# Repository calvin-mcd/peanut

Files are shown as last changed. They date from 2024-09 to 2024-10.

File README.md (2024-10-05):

# peanut

alice like 30% inspired by littol and tsuru. Case design, layout and concept by calumwri. Pcb by calvin0563

## Layout

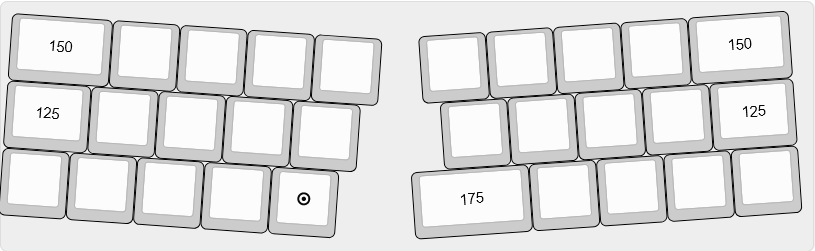
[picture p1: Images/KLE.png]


[Link](http://www.keyboard-layout-editor.com/#/gists/5c7a74c8b3bbc1b4ac3f81c209dc5aab)

## Case & Plate

Case and plate files are included in the respective folder.

The case requires m2x3mm heat set inserts and 3mm silicone inserts for the feet.

## Firmware

Flash file and source code included in the respective folder.

## Pictures

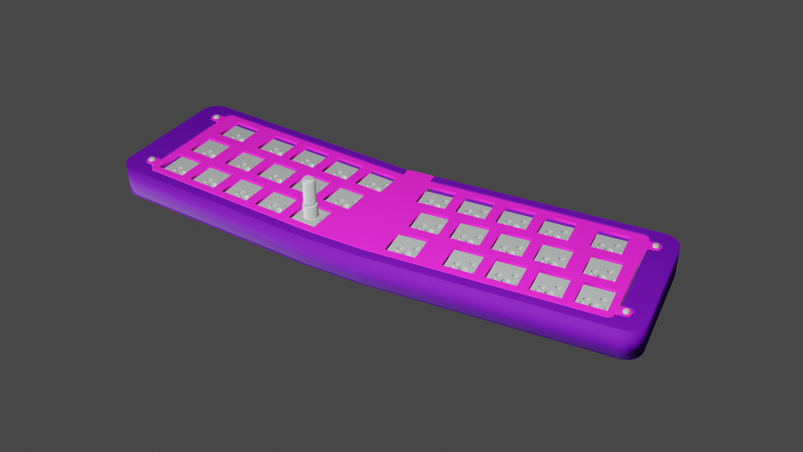
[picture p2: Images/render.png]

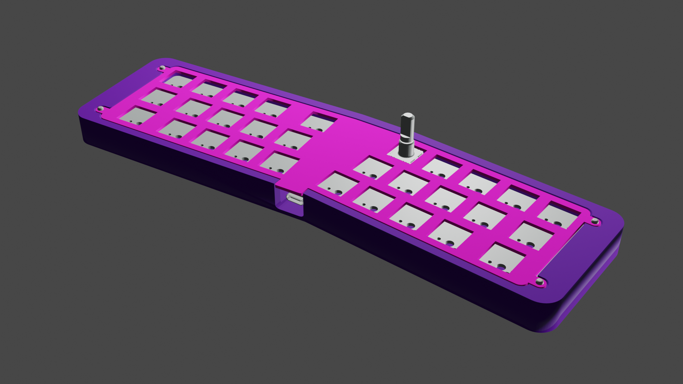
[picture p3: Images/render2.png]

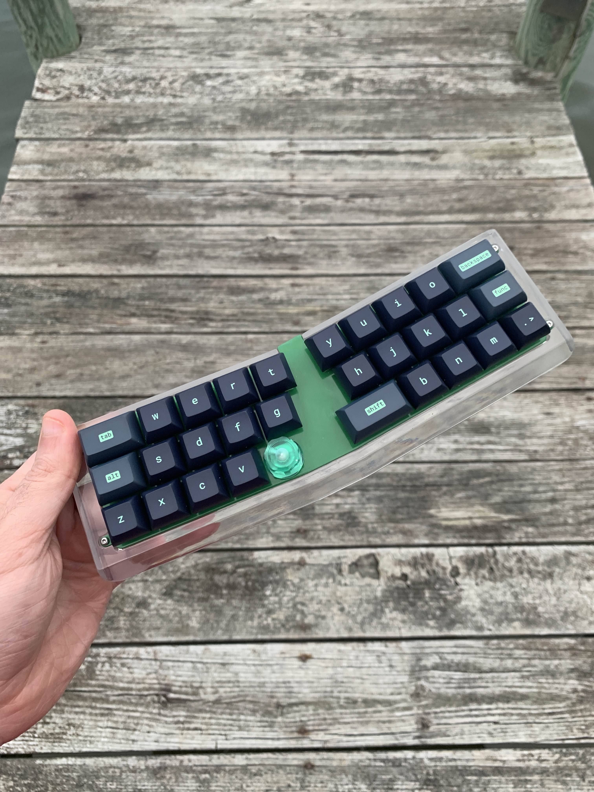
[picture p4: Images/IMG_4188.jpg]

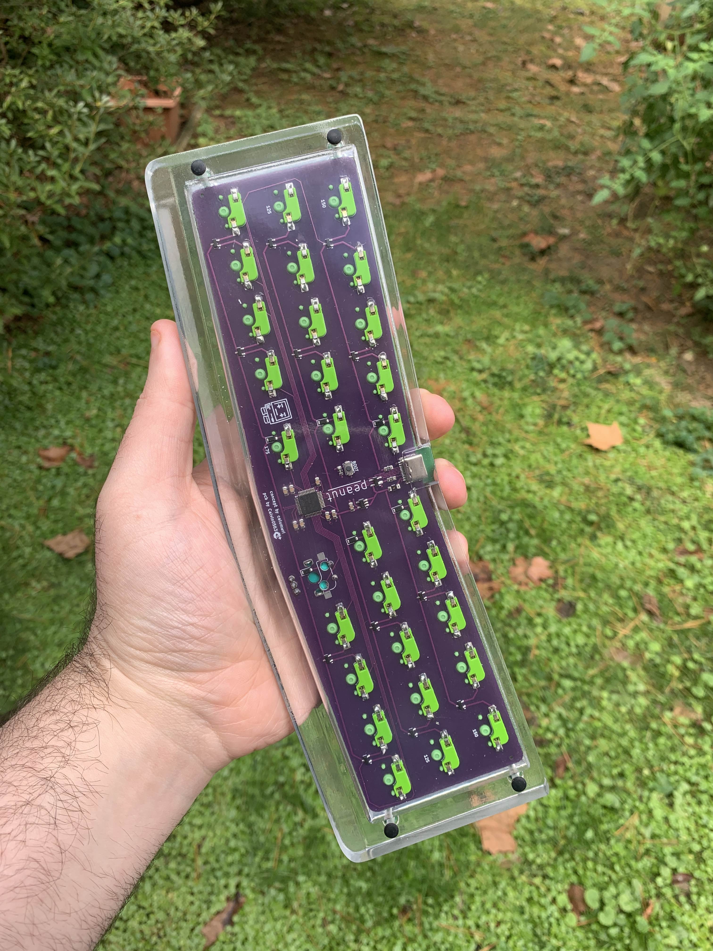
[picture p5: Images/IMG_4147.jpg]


## Todo

- [X] order & test pcb
- [X] test case
- [X] create firmware

## Disclaimer

This PCB has been fully tested and confirmed to work. The members of the PCB development team are however not liable if you end up with a non-functional pcb. Order at your own risk. Support will not be provided but pull requests will be reviewed and possibly accepted.

## License

This project is released under the GPL v3 License. Please refer to the LICENCE file.

## Credits

As always big thanks to the many people who helped me and inspired this board!

Any questions, contact Calvin0563 on Discord.

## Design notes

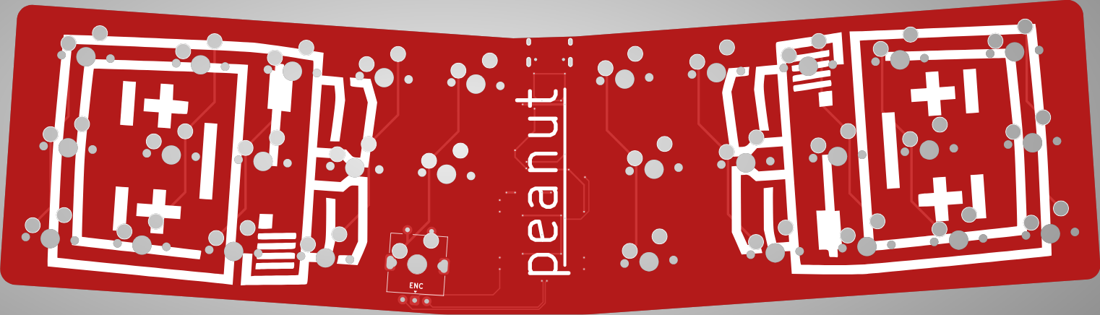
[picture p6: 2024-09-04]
Images/top.png

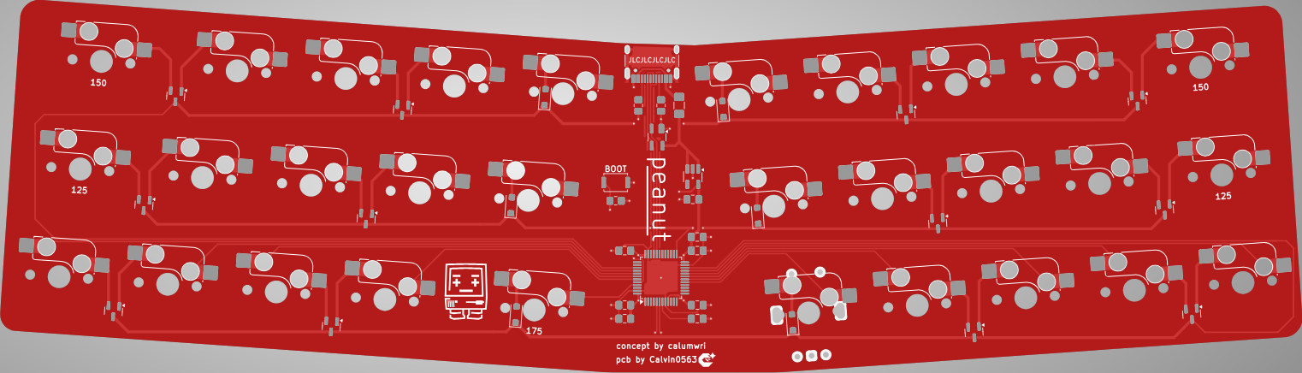
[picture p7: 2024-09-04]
Images/bottom.png

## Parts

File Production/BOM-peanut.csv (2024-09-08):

Comment | Designator | Footprint | LCSC
5.1k | R2,R3 | R_0805_2012Metric_Pad1.20x1.40mm_HandSolder | C118848
1nF | C8 | C_0805_2012Metric_Pad1.18x1.45mm_HandSolder | C7419428
500mA | F1 | Fuse_1206_3216Metric_Pad1.42x1.75mm_HandSolder | C135341
10uF | C6 | C_0805_2012Metric_Pad1.18x1.45mm_HandSolder | C15850
10k | R1 | R_0805_2012Metric_Pad1.20x1.40mm_HandSolder | C17414
100nF | C1,C2,C3,C4,C5,C7 | C_0805_2012Metric_Pad1.18x1.45mm_HandSolder | C28233
PRTR5V0U2X | U3 | SOT-143_Handsoldering | C2827688
USB_C_Receptacle_USB2.0 | J1 | USB_C_Receptacle_HRO_TYPE-C-31-M-12 | C165948
AP2112K-3.3 | U2 | SOT-23-5_HandSoldering | C3021085
BAV70_Small | D1,D10,D11,D12,D13,D14,D2,D3,D4,D7,D8,D9 | SOT-23 | C5184417
SKQGABE010 | SW2 | SW_Push_SPST_NO_Alps_SKRK | C561519
D_Small | D15,D16,D25,D26,D5,D6 | D_SOD-123F | C64898
STM32F072C8Tx | U1 | LQFP-48_7x7mm_P0.5mm | C80488

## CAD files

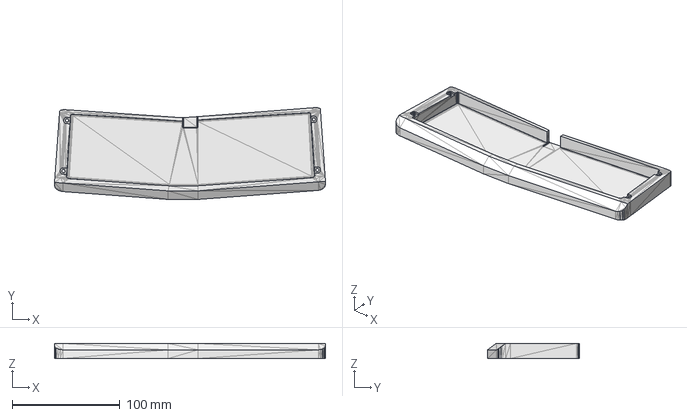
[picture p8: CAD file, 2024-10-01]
Case & Plate/peanut2.step
251.7 x 85.3 x 14.1 mm

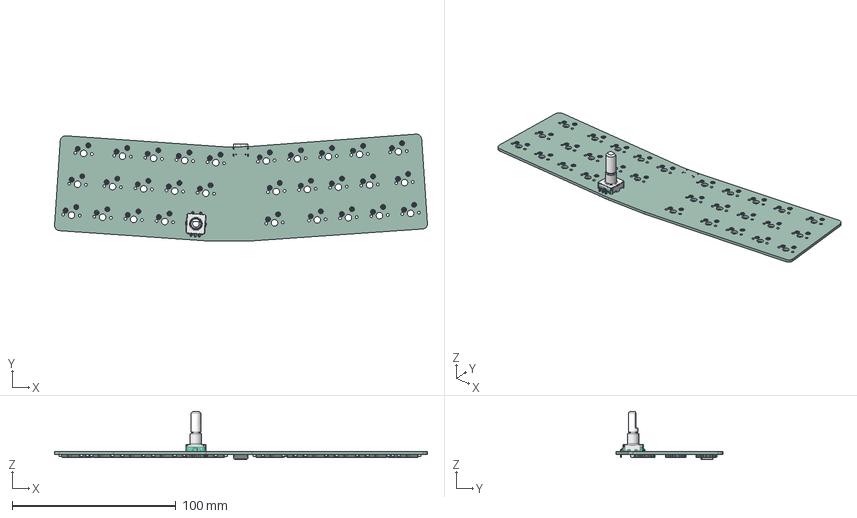
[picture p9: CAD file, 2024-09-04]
Project/peanut.step
227.9 x 65.3 x 29.4 mm
(Unsaved)
Kailh Hotswap v2 x 30
CON_TYPE-C-31-M-12 v3
_autosave-tsuru alice_PCB

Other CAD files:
Case & Plate/peanut2.stl

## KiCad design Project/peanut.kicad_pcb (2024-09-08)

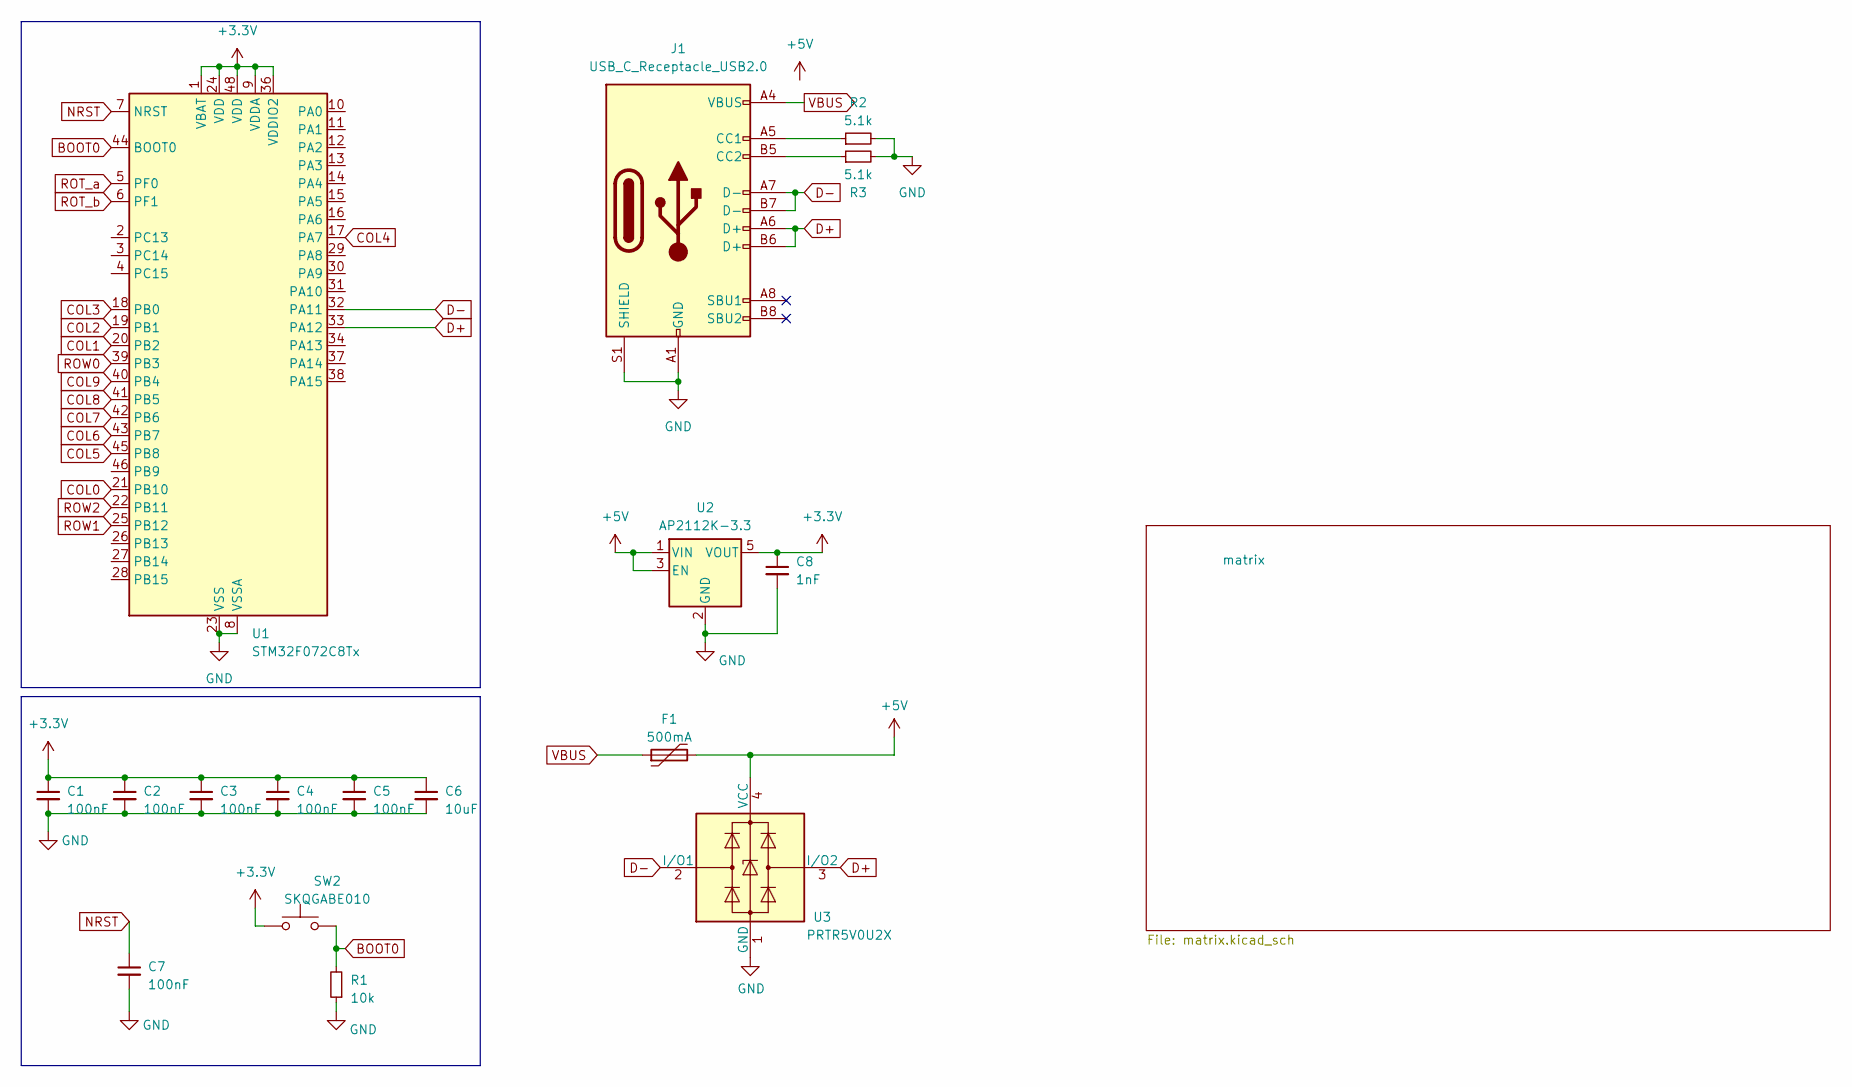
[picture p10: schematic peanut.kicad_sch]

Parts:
C1, C2, C3, C4, C5, C7: 100nF; C_0805_2012Metric_Pad1.18x1.45mm_HandSolder
C6: 10uF; C_0805_2012Metric_Pad1.18x1.45mm_HandSolder
C8: 1nF; C_0805_2012Metric_Pad1.18x1.45mm_HandSolder; LCSC Part Number C129637
F1: 500mA; Fuse_1206_3216Metric_Pad1.42x1.75mm_HandSolder; LCSC C135341
J1: USB_C_Receptacle_USB2.0; USB_C_Receptacle_HRO_TYPE-C-31-M-12; LCSC Part Number C3001293
R1: 10k; R_0805_2012Metric_Pad1.20x1.40mm_HandSolder
R2, R3: 5.1k; R_0805_2012Metric_Pad1.20x1.40mm_HandSolder
SW2: SKQGABE010; SW_Push_SPST_NO_Alps_SKRK; LCSC C115351
U1: STM32F072C8Tx; LQFP-48_7x7mm_P0.5mm
U2: AP2112K-3.3; SOT-23-5_HandSoldering; MPN AP2112K-3.3; LCSC Part Number C3021085
U3: PRTR5V0U2X; SOT-143_Handsoldering; LCSC C2827688

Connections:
+3.3V: C1.1, C2.1, C3.1, C4.1, C5.1, C6.1, C8.1, SW2.1, U1.1 (VBAT), U1.9 (VDDA), U1.24 (VDD), U1.36 (VDDIO2), U1.48 (VDD), U2.5 (VOUT)
+5V: F1.2, U2.1 (VIN), U2.3 (EN), U3.4 (VCC)
BOOT0: R1.2, SW2.2, U1.44 (BOOT0)
COL0: U1.21 (PB10); also elsewhere on the board
COL1: U1.20 (PB2); also elsewhere on the board
COL2: U1.19 (PB1); also elsewhere on the board
COL3: U1.18 (PB0); also elsewhere on the board
COL4: U1.17 (PA7); also elsewhere on the board
COL5: U1.45 (PB8); also elsewhere on the board
COL6: U1.43 (PB7); also elsewhere on the board
COL7: U1.42 (PB6); also elsewhere on the board
COL8: U1.41 (PB5); also elsewhere on the board
COL9: U1.40 (PB4); also elsewhere on the board
D+: J1.A6 (D+), J1.B6 (D+), U1.33 (PA12), U3.3 (I/O2)
D-: J1.A7 (D-), J1.B7 (D-), U1.32 (PA11), U3.2 (I/O1)
GND: C1.2, C2.2, C3.2, C4.2, C5.2, C6.2, C7.2, C8.2, J1.A1 (GND), J1.A12 (GND), J1.B1 (GND), J1.B12 (GND), J1.S1 (SHIELD), R1.1, R2.2, R3.2, U1.8 (VSSA), U1.23 (VSS), U1.35 (VSS), U1.47 (VSS), U2.2 (GND), U3.1 (GND); also elsewhere on the board
NRST: C7.1, U1.7 (NRST)
unnamed: J1.A5 (CC1), R2.1
unnamed: J1.B5 (CC2), R3.1
ROT_a: U1.5 (PF0); also elsewhere on the board
ROT_b: U1.6 (PF1); also elsewhere on the board
ROW0: U1.39 (PB3); also elsewhere on the board
ROW1: U1.25 (PB12); also elsewhere on the board
ROW3: U1.22 (PB11); also elsewhere on the board
VBUS: F1.1, J1.A4 (VBUS), J1.A9 (VBUS), J1.B4 (VBUS), J1.B9 (VBUS)

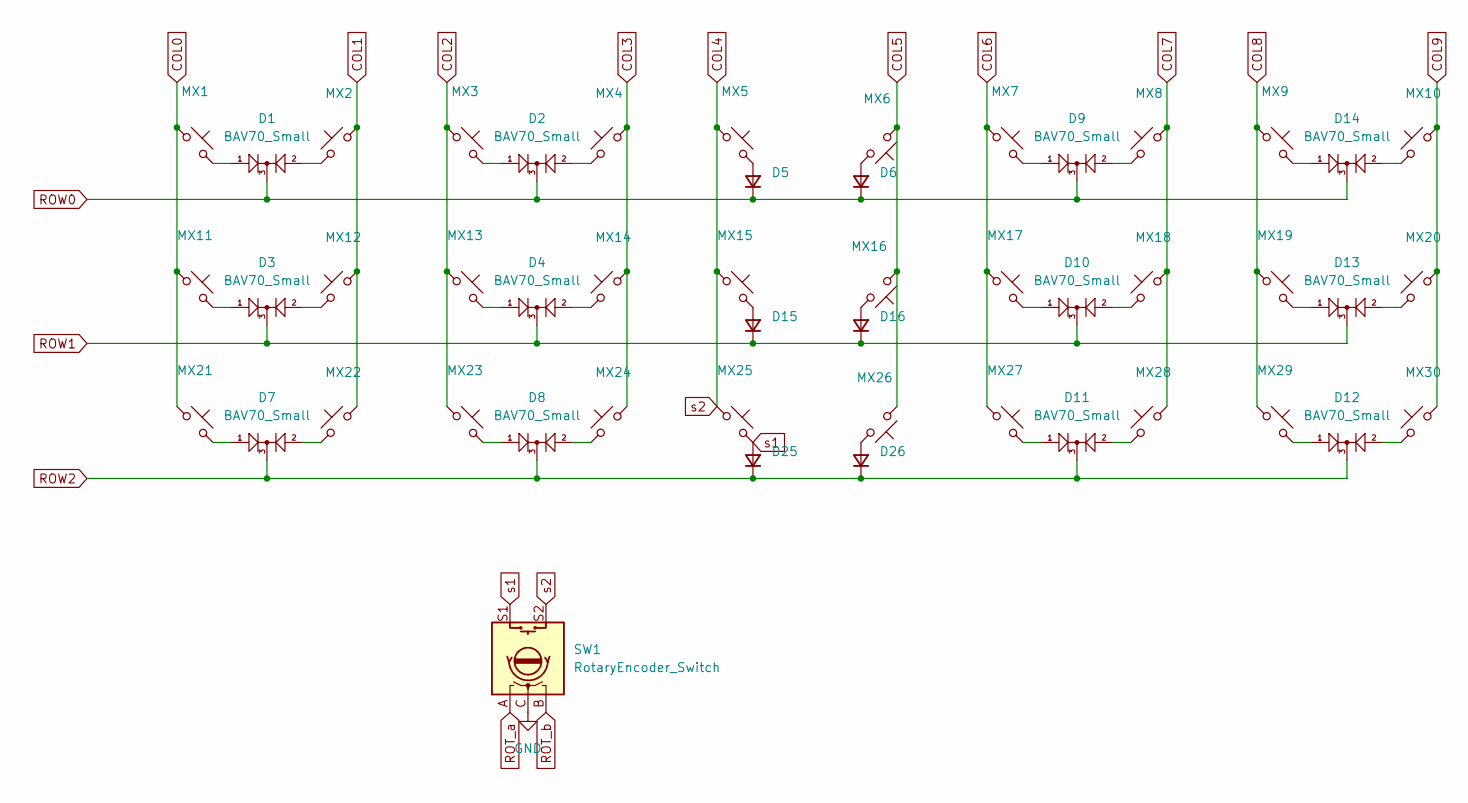
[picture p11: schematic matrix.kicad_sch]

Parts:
D1, D2, D3, D4, D7, D8, D9, D10, D11, D12, D13, D14: BAV70_Small; SOT-23
D5, D6, D15, D16, D25, D26: D_Small; D_SOD-123F
MX1, MX10: MX_SW_HS; SW_MX_HS_CPG151101S11_1.5u
MX2, MX3, MX4, MX5, MX6, MX7, MX8, MX9, MX12, MX13, MX14, MX15, MX16, MX17, MX18, MX19, MX21, MX22, MX23, MX24, MX25, MX27, MX28, MX29, MX30: MX_SW_HS; SW_MX_HS_CPG151101S11_1u
MX11, MX20: MX_SW_HS; SW_MX_HS_CPG151101S11_1.25u
MX26: MX_SW_HS; SW_MX_HS_CPG151101S11_1.75u
SW1: RotaryEncoder_Switch; ROT_Alps_EC11E-Switch

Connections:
COL0: MX1.1, MX11.1, MX21.1; also elsewhere on the board
COL1: MX2.2, MX12.2, MX22.2; also elsewhere on the board
COL2: MX3.1, MX13.1, MX23.1; also elsewhere on the board
COL3: MX4.2, MX14.2, MX24.2; also elsewhere on the board
COL4: MX5.1, MX15.1, MX25.1, SW1.S2; also elsewhere on the board
COL5: MX6.1, MX16.1, MX26.1; also elsewhere on the board
COL6: MX7.1, MX17.1, MX27.1; also elsewhere on the board
COL7: MX8.2, MX18.2, MX28.2; also elsewhere on the board
COL8: MX9.1, MX19.1, MX29.1; also elsewhere on the board
COL9: MX10.2, MX20.2, MX30.2; also elsewhere on the board
GND: SW1.C; also elsewhere on the board
unnamed: D1.1 (A1), MX1.2
unnamed: D1.2 (A2), MX2.1
unnamed: D2.1 (A1), MX3.2
unnamed: D2.2 (A2), MX4.1
unnamed: D3.1 (A1), MX11.2
unnamed: D3.2 (A2), MX12.1
unnamed: D4.1 (A1), MX13.2
unnamed: D4.2 (A2), MX14.1
unnamed: D5.2 (A), MX5.2
unnamed: D6.2 (A), MX6.2
unnamed: D7.1 (A1), MX21.2
unnamed: D7.2 (A2), MX22.1
unnamed: D8.1 (A1), MX23.2
unnamed: D8.2 (A2), MX24.1
unnamed: D9.1 (A1), MX7.2
unnamed: D9.2 (A2), MX8.1
unnamed: D10.1 (A1), MX17.2
unnamed: D10.2 (A2), MX18.1
unnamed: D11.1 (A1), MX27.2
unnamed: D11.2 (A2), MX28.1
unnamed: D12.1 (A1), MX29.2
unnamed: D12.2 (A2), MX30.1
unnamed: D13.1 (A1), MX19.2
unnamed: D13.2 (A2), MX20.1
unnamed: D14.1 (A1), MX9.2
unnamed: D14.2 (A2), MX10.1
unnamed: D15.2 (A), MX15.2
unnamed: D16.2 (A), MX16.2
unnamed: D26.2 (A), MX26.2
ROT_a: SW1.A; also elsewhere on the board
ROT_b: SW1.B; also elsewhere on the board
ROW0: D1.3 (K), D2.3 (K), D5.1 (K), D6.1 (K), D9.3 (K), D14.3 (K); also elsewhere on the board
ROW1: D3.3 (K), D4.3 (K), D10.3 (K), D13.3 (K), D15.1 (K), D16.1 (K); also elsewhere on the board
ROW3: D7.3 (K), D8.3 (K), D11.3 (K), D12.3 (K), D25.1 (K), D26.1 (K); also elsewhere on the board
s1: D25.2 (A), MX25.2, SW1.S1

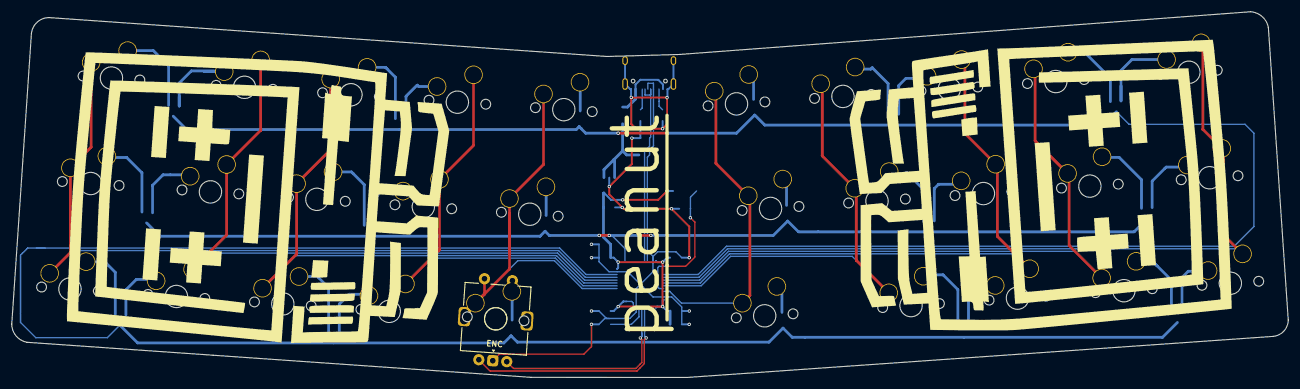
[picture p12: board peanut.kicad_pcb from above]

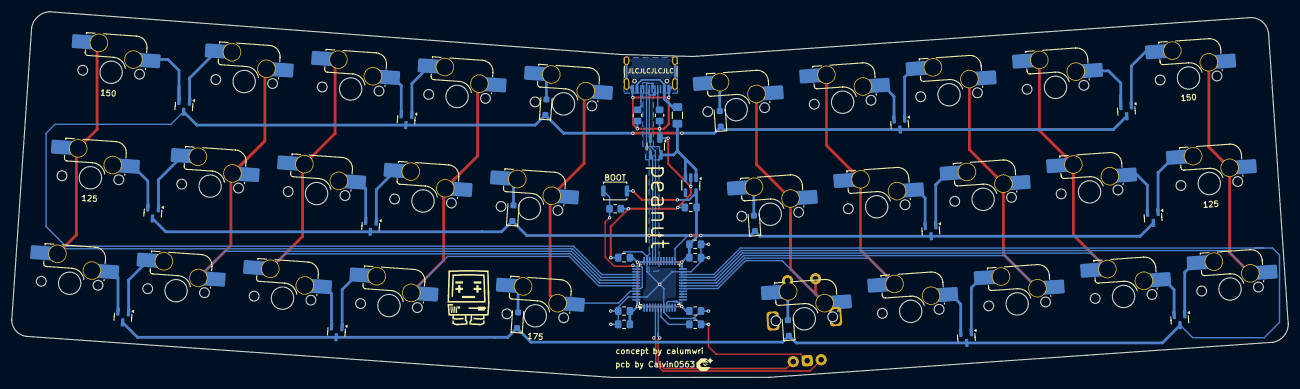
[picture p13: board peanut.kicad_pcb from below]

Board: 2 copper layers, 227.9 x 65.3 mm, 66 parts (65 on the bottom side), 55 nets.

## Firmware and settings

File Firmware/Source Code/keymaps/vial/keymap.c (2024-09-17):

#include QMK_KEYBOARD_H

const uint16_t PROGMEM keymaps[][MATRIX_ROWS][MATRIX_COLS] = {
    [0] = LAYOUT(
        KC_NO,   KC_NO,   KC_NO,   KC_NO,   KC_NO,   KC_NO,   KC_NO,   KC_NO,   KC_NO,   KC_NO,
        KC_NO,   KC_NO,   KC_NO,   KC_NO,   KC_NO,   KC_NO,   KC_NO,   KC_NO,   KC_NO,   KC_NO,
        KC_NO,   KC_NO,   KC_NO,   KC_NO,   KC_NO,   KC_NO,   KC_NO,   KC_NO,   KC_NO,   KC_NO
      ),
    [1] = LAYOUT(
        KC_NO,   KC_NO,   KC_NO,   KC_NO,   KC_NO,   KC_NO,   KC_NO,   KC_NO,   KC_NO,   KC_NO,
        KC_NO,   KC_NO,   KC_NO,   KC_NO,   KC_NO,   KC_NO,   KC_NO,   KC_NO,   KC_NO,   KC_NO,
        KC_NO,   KC_NO,   KC_NO,   KC_NO,   KC_NO,   KC_NO,   KC_NO,   KC_NO,   KC_NO,   KC_NO
    ),
    [2] = LAYOUT(
        KC_NO,   KC_NO,   KC_NO,   KC_NO,   KC_NO,   KC_NO,   KC_NO,   KC_NO,   KC_NO,   KC_NO,
        KC_NO,   KC_NO,   KC_NO,   KC_NO,   KC_NO,   KC_NO,   KC_NO,   KC_NO,   KC_NO,   KC_NO,
        KC_NO,   KC_NO,   KC_NO,   KC_NO,   KC_NO,   KC_NO,   KC_NO,   KC_NO,   KC_NO,   KC_NO
    ),
    [3] = LAYOUT(
        KC_NO,   KC_NO,   KC_NO,   KC_NO,   KC_NO,   KC_NO,   KC_NO,   KC_NO,   KC_NO,   KC_NO,
        KC_NO,   KC_NO,   KC_NO,   KC_NO,   KC_NO,   KC_NO,   KC_NO,   KC_NO,   KC_NO,   KC_NO,
        KC_NO,   KC_NO,   KC_NO,   KC_NO,   KC_NO,   KC_NO,   KC_NO,   KC_NO,   KC_NO,   KC_NO
    ),
    [4] = LAYOUT(
        KC_NO,   KC_NO,   KC_NO,   KC_NO,   KC_NO,   KC_NO,   KC_NO,   KC_NO,   KC_NO,   KC_NO,
        KC_NO,   KC_NO,   KC_NO,   KC_NO,   KC_NO,   KC_NO,   KC_NO,   KC_NO,   KC_NO,   KC_NO,
        KC_NO,   KC_NO,   KC_NO,   KC_NO,   KC_NO,   KC_NO,   KC_NO,   KC_NO,   KC_NO,   KC_NO
    ),
    [5] = LAYOUT(
        KC_NO,   KC_NO,   KC_NO,   KC_NO,   KC_NO,   KC_NO,   KC_NO,   KC_NO,   KC_NO,   KC_NO,
        KC_NO,   KC_NO,   KC_NO,   KC_NO,   KC_NO,   KC_NO,   KC_NO,   KC_NO,   KC_NO,   KC_NO,
        KC_NO,   KC_NO,   KC_NO,   KC_NO,   KC_NO,   KC_NO,   KC_NO,   KC_NO,   KC_NO,   KC_NO
    )

};

#ifdef ENCODER_MAP_ENABLE
const uint16_t PROGMEM encoder_map[][NUM_ENCODERS][NUM_DIRECTIONS] = {
    [0] =   { ENCODER_CCW_CW(KC_VOLD, KC_VOLU) },
    [1] =   { ENCODER_CCW_CW(_______, _______) },
    [2] =   { ENCODER_CCW_CW(_______, _______) },
    [3] =   { ENCODER_CCW_CW(_______, _______) },
    [4] =   { ENCODER_CCW_CW(_______, _______) },
    [5] =   { ENCODER_CCW_CW(_______, _______) }

};
#endif

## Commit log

2024-09-05 added case renders
2024-10-01 case & plate file added, readme update
    [peanut2.step, peanut2.stl]
